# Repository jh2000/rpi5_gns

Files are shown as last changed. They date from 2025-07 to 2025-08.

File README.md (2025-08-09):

# RPi5 HAT+ for GNS AIS and ADS-B Modules

# Aktuelle Fehler
- Im aktuellen Layout ist ein Kreuzungsfehler, dadurch wird UART_Rx an Pin 10 vom GNS5851 mit F_ind verbunden.  
Wird die Platine so gefertigt, muss die Verbindung aufgetrennt werden (direkt vor dem GNS5851, zum Glück sehr gut erreichbar) und manuell eine Brücke von Pin 5 zu R7 gelegt werden.
- Der RX-Pin vom AIS-Modul ist mit GPIO 7 anstelle 8 verbunden, daher ist keine Kommunikation vom RPi zum AIS-Modul möglich. Ein Workaround ist, die nebeneinander liegenden Pins GPIO 7 und 8 (Pins 24 und 26) zu verbinden.
- Das Loch der GPS-Antenne ist scheinbar nicht richtig positioniert, es passt aber noch ausreichend gut. Vermutlich sind die Abstandsmaße von der falschen Seite.
- die Adressierung des PCF8574 ist invertiert On=Low.
- die Seitenpins der ADS-B und AIS Empfängers sind gem. Datenblatt angelegt, sie lassen sich aber nur per Heißluft anlöten, da man von der Seite nicht mit einem Lötkolben an die Pins kommt. Dazu sind sie sehr exakt zu positionieren. Am besten zuerst diese 4 anlöten und prüfen ob etwas gebrückt wurde.
- am AIS-Empfänger sind zusätzliche Lötpunkte an den Gehäuseseiten auf der Platine, die sind aber überflüssig. Ebenso werden ohne Daisy-Chaining die 4 Seitenpins nicht benötigt und könnten auch weg bleiben.

# Allgemein
Schaltplan und Platinendesign mit KiCAD 9.0.  
Im Repo zu finden sind die Projektdateien sowie footprints und symbole der Bauteile der Firma GNS.  
Die RPi HAT Footprints und Symbole stammen aus einem anderen Repo, siehe Links.  
Es gibt ebenso eine Adapterplatine um die AIS/ADSB-Platinen mit allen Pins auf eine Pfostenleiste zu bekommen um z.B. einen ESP32/Arduino o.ä. zu verwenden.  
GNS bietet verschiedene Stufen von Features, die Platinen sind Pinkompatibel, somit lassen sich alternativ zum GNS5894T auch GNS5894TAC oder der abgespeckte GNS 5892R verwenden.  
Das GPS-Modul ist nicht Pinkompatibel mit den anderen. Für AIS gibt es zur Zeit nur ein Modul.  
Anstelle eines RPi5 kann weitestgehend auch ein RPi4 verwendet werden. Es gibt aber im Detail Unterschiede zu beachten, auf die ich hier erst mal nicht näher eingehe.

# Pro&Contra
+ \+ CPU quasi idle
+ \+ dadurch wesentlich energieeffizienter gegenüber SDR/DVB-Sticks
+ \+ mehr Platz für SDR für Schiff-&Flugfunk
+ \- hoher Preis
+ \- nicht alle Feeder kompatibel

# Disclaimer
~~Die Designs sind noch ungeprüft und befinden sich zur Zeit in der Platinenfertigung. Es ist daher ein starker 'work in progress' ohne validierte Layouts.~~  
Die Designs habe ich jeweils einmal fertigen lassen. Dabei sind die oben genannten kleineren Fehler aufgefallen. Grundsätzlich funktionieren die Platinen im aktuellen Zustand.  

**Ich bin eine Privatperson und stehe nicht mit Firma GNS, rpi, jlcpcb oder Anderen in kommerzieller Verbindung**  
**Für Schäden übernehme ich keine Haftung**  

# Beschreibung der Platine
Benutzt werden GNS701 als GPS-Empfänger mit PPS Ausgang, GNS5851 als AIS-Empfänger sowie GNS5894T als ADSB Empfänger.  
Des Weiteren sind ein EEPROM für die HAT+ Erkennung, sowie ein I2C GPIO-Expander (PCF8574AT) vorhanden um die Reset/Steuereingänge anzusteuern.  
Die Adresse des GPIO-Expanders kann über DIP-Schalter frei gewählt werden.  
Das EEPROM zur automatschen HAT Erkennung (z.B. CAT24C128) hat Lötpads um den schreibschutz und die Adresse zu steuern. Standardmäßig ist 0x50. Gem. spezifikation würde auch 0x51 gehen.
Sollte das HAT zusammen mit anderen Verwendet werden muss geprüft werden, dass es keinen Konflikt der Adresse oder Pins gibt.
Aus Platz- und Komplexitätsgründen habe ich auf viele Bauteile verzichtet. Entsprechend fehlen Stütz-/Filterkapazitäten, Pegelbegrenzer usw.  
Es lassen sich theoretisch 2 der AIS Empfänger Chips Daisy-Chainen um auf Kanal A und B zeitgleich zu lauschen. Mit mehr Durchkontaktierungen und den Signalteilern/Filtern/Verstärkern gem. Herstellervorgabe könnte es noch knapp auf die Platine drauf passen. 

# Verdrahtung
Der ADSB-Empfänger hängt an UART0. Hier werden die Flusssteuerung über CTS/RTS (GPIO 16/17, Pin 36/11) mit angesteuert.  
Der AIS-Empfänger hängt an UART3.  
Der GPS-Empfänger hängt an UART4, die PPS Funktion an GPIO26/Pin 37.  

# Konfiguration
die HAT+ Erkennung hat zur Zeit keine funktionalen Benefits, daher müssen alle Einstellungen/Programme selbst getätigt/geladen werden.  
Sobald die Hardware lauffähig getestet ist lassen sich zumindest die overlay Anteile und Pinsteuerungen so automatisieren.
Ich verwende Debian 12.

**/boot/config.txt**
```
dtoverlay=pps-gpio,gpiopin=26  
dtoverlay=uart0-pi5,ctsrts  
dtoverlay=uart3-pi5  
dtoverlay=uart4-pi5
dtparam=i2c1=on
dtoverlay=pcf857x,addr=38 # Wohl obsolet
```
**/etc/default/gpsd**
```
DEVICES="/dev/ttyAMA4 /dev/pps0"
GPSD_OPTIONS="-s 9600 -n"
```

**/etc/ntpsec/ntp.conf**
```
server 127.127.22.0 minpoll 4 maxpoll 4
fudge 127.127.22.0 refid PPS
fudge 127.127.22.0 flag3 1 # enable kernel PLL/FLL clock discipline

server 127.127.28.0 minpoll 4 maxpoll 4 prefer # PPS requires at least one preferred peer
fudge 127.127.28.0 refid GPS
fudge 127.127.28.0 time1 +0.130 # coarse offset due to the UART delay

```
**/etc/ser2net.yaml**
```
connection: &adsb01
    accepter: tcp,4000
    enable: on
    options:
      kickolduser: true
    connector: serialdev,/dev/ttyAMA0,3000000n81,local rtscts # Bei Textmodus
    #    921600n81,local rtscts Bei HULC
connection: &ais01
    accepter: tcp,2001
    enable: on
    options:
      kickolduser: true
    connector: serialdev,/dev/ttyAMA3,115200n81,local
connection: &gps01
    accepter: tcp,3002
    enable: on
    options:
      kickolduser: true
    connector: serialdev,/dev/ttyAMA4,9600n81,local

```
# Peripherie
**Steuerchip PCF8574AT**  
Der GPIO-Expander steuert folgende Funktionen:

|Pin|Funktion|Beschreibung|
|-|-|-|
|P0|ADS-B Reset|low für reset des GNS5894T Receivers, float/high für Betrieb|
|P1|ADS-B Modus|wenn J3 auf 2-3 gebrückt, steuerung des Modus (float/high=Text, low=Binär)
|P2|GPS Reset|low für reset des GNS701 Receivers, float/high für Betrieb|
|P3|GPS Enable|float/high um GNS701 zu aktivieren, low für Standby|
|P4|AIS Reset|low für reset des GNS5851 Receivers, float/high für Betrieb|
|P5|NC|Nicht verbunden|
|P6|NC|Nicht verbunden|
|P7|NC|Nicht verbunden|

Die Adresse des GPIO-Expanders kann über den Dipschalter SW1 zwischen 0x38 und 0x3F frei eingestellt werden.  
Zu beachten ist, dass die DIP-Switche gegen Masse schalten, also On = Masse. Entsprechend ist alle auf On = 0x38 und alle auf Off = 0x3F!

**AIS Modul GNS5851**  
Das AIS-Modul verwendet 115200-8-N-1 für die serielle Kommunikation.  
Beim Power on oder sobald das Modul resetet wird, wird die Version ausgeben:  
$PGNS,0,V,GNS5851,23.20.1,1.0-1,H,S01*08

Es gibt folgende Befehle auf die reagiert wird, jeweils im NMEA 0183 Standard:
Versionsabfrage, $PGNS,V*70<CR><LF>  
Betriebsmodus, $PGNS,M,A*06, $PGNS,M,B*07 oder $PGNS,M,H*0D für nur Kanal *A*, nur *B* oder Kanal*H*opping.  
Nach einem Reset wird die Version ausgegeben.  

**ADS-B Modul GNS5894TAC**  
DAS ADS-B Modul verwendet je nach Einstellung HULC oder Textprotokoll für die ADS-B Daten mit entsprechend 921600 oder 3000000 Baud, je 8 N 1.  
Aufgrund der Datenrate ist die Verwendung von RTS/CTS Handshakes empfohlen.  
Im HULC Modus wird sekündlich ein Datenpaket übertragen, im Textmodus dagegen gibt es abseits empfangener Signale keinerlei Status, auch nicht beim Reset/Einschalten.  
Die Funktionsfähigkeit kann hier getestet werden indem "#00" gesendet wird.

Das Modul empfängt auf dem 2. UART Port die GPS Daten vom GNS701 und erwartet diese mit 9600 Baud und einer Position pro Sekunde. Benutzt wird dafür der 2. Ausgang des GPS-Empfängers.

Es gibt folgende Befehle, je nach Protokoll:
Versionsabfrage, #00<CR><LF>  
Betriebsmodus abfragen, #43<CR><LF>  
Betriebsmodus setzen, #43-XY<CR><LF> wobei X 1 für MLAT sowie 8 für RSSI ist und Y die Ausgabe steuert (0 Mode S off, 1 'reserved, do not use', 2 Output all Mode-S  & Mode-A/C data, default, 3 nur ADS-B und 4 nur ADS-B mit gültigem CRC)  
Reset, #FF<CR><LF>  

**GPS Modul GNS701**  
Bei der Konfiguration des GPS-Empfängers zu beachten, dass die Daten des 2. Ausganges (TX1) an das ADS-B Modul gehen.  
Standardmäßig werden 9600 Baud, 8-N-1 mit einer Position pro Sekunde  benutzt für beide Schnittstellen.  
Solange das Modul im Reset oder Standby zustand ist, bleibt die 3D-Fix LED aus. Solange das Modul ansonsten im Normalbetrieb ist, sollte mindestens einmal pro Sekunde etwas im Terminal zu finden sein, im Takt mit dem Blinken der 3D-Fix LED.

Die Konfiguration basiert auf der MediaTek Befehlsreferenz. Entsprichend sollten die dortigen Befehle gehen  
Testpaket: $PMTK000*32<CR><LF>  
Versionsabfrage: $PMTK604*6D<CR><LF>  

**Allgemein**  
Die Module geben über die UART-Schnittstelle standardmäßig (lesbaren) Text aus. Es kann für ADS-B aber auch das HULC/Beast Binärformat anstelle von AVR benutzt werden.
Alle üblichen Programme können die Daten entsprechend lesen, bis auf modesdeco2, welches nur Funkrohdaten verarbeiten kann.  

Erfolgreich getestete feeder für AIS mit dem GNS5851:  
+ sxfeeder
+ AIS-Catcher

Erfolgreich getestete feeder für ADS-B mit dem GNS5894T:  
+ rbfeeder (radarbox)
+ feed-adsbx (adsbexchange)
+ mlat-client (adsbexchange)
+ fr24feed (flightradar)

Das GPS-Modul bietet GPS und PPS Daten für z.B. gpsd.  

In der Zielarchitektur verwende ich gpsd, ser2net und alle Feeder der jeweiligen Platformen.  
Dabei werden die AIS und ADS-B rohdaten via ser2net vom jeweiligen primärprogramm (AIS-Catcher, rbfeeder) gelesen und stellen diese Daten dann an sekundärfeeder (sxfeeder, feed-adsb usw...) bereit.
ser2net hat sich als praktisch erwiesen, da es sich einfach debuggen lässt indem man z.b. per nc oder telnet verbinden kann.  
gpsd und ntpd stellen dem System die genauen Zeitdaten bereit. Wer es richtig übertreiben will, kann das Design anpassen und einen RTK fähigen GPS Empfänger einbauen.

Das HAT sollte HAT+ Spezifikationen erfüllen, dies ist aber noch nicht bestätigt, im Design ist testweise ein HAT+ Logo angebracht.

Im aktuellen Design gegenüber dem Referenzentwurf fehlt der Schlitz um an einen der CSI Ports zu kommen. Da dies ggf. Bestandteil der HAT+ Hardwareforderungen ist, muss dies noch korrigiert werden.  
Diese Abweichung zeigt KiCAD entsprechend als Warnung an.  
Des Weiteren werden die je 4 zusätzlichen Pads der AIS und ADS-B Module als zu eng für die Standardabstände geflaggt. Somit sollten anfangs 1+3+3 Warnungen bzw. Fehler auftreten, welche ignoriert werden können.

# Linksammlung:

+ HAT+ Spezifikation: [https://datasheets.raspberrypi.com/hat/hat-plus-specification.pdf]
+ GPS: [https://www.gns-electronics.de/product/gns-701/]
+ AIS: [https://www.gns-electronics.de/product/gns-5851-ais-module/]
+ AIS Daisy-Chaining: [https://www.gns-electronics.de/wp-content/uploads/2025/05/GNS5851_AppNote_2ch-Receiver-V0.9.pdf]
+ ADS-B: [https://www.gns-electronics.de/product/gns-5894-highperformance-ads-b-modul/]
+ RPi HAT Template: [https://github.com/devbisme/RPi_Hat_Template]
+ Prototypenfertiger: [https://jlcpcb.com/]
+ PMTK Protokoll: [https://cdn.sparkfun.com/assets/f/0/9/1/c/PMTK_Protocol.pdf]

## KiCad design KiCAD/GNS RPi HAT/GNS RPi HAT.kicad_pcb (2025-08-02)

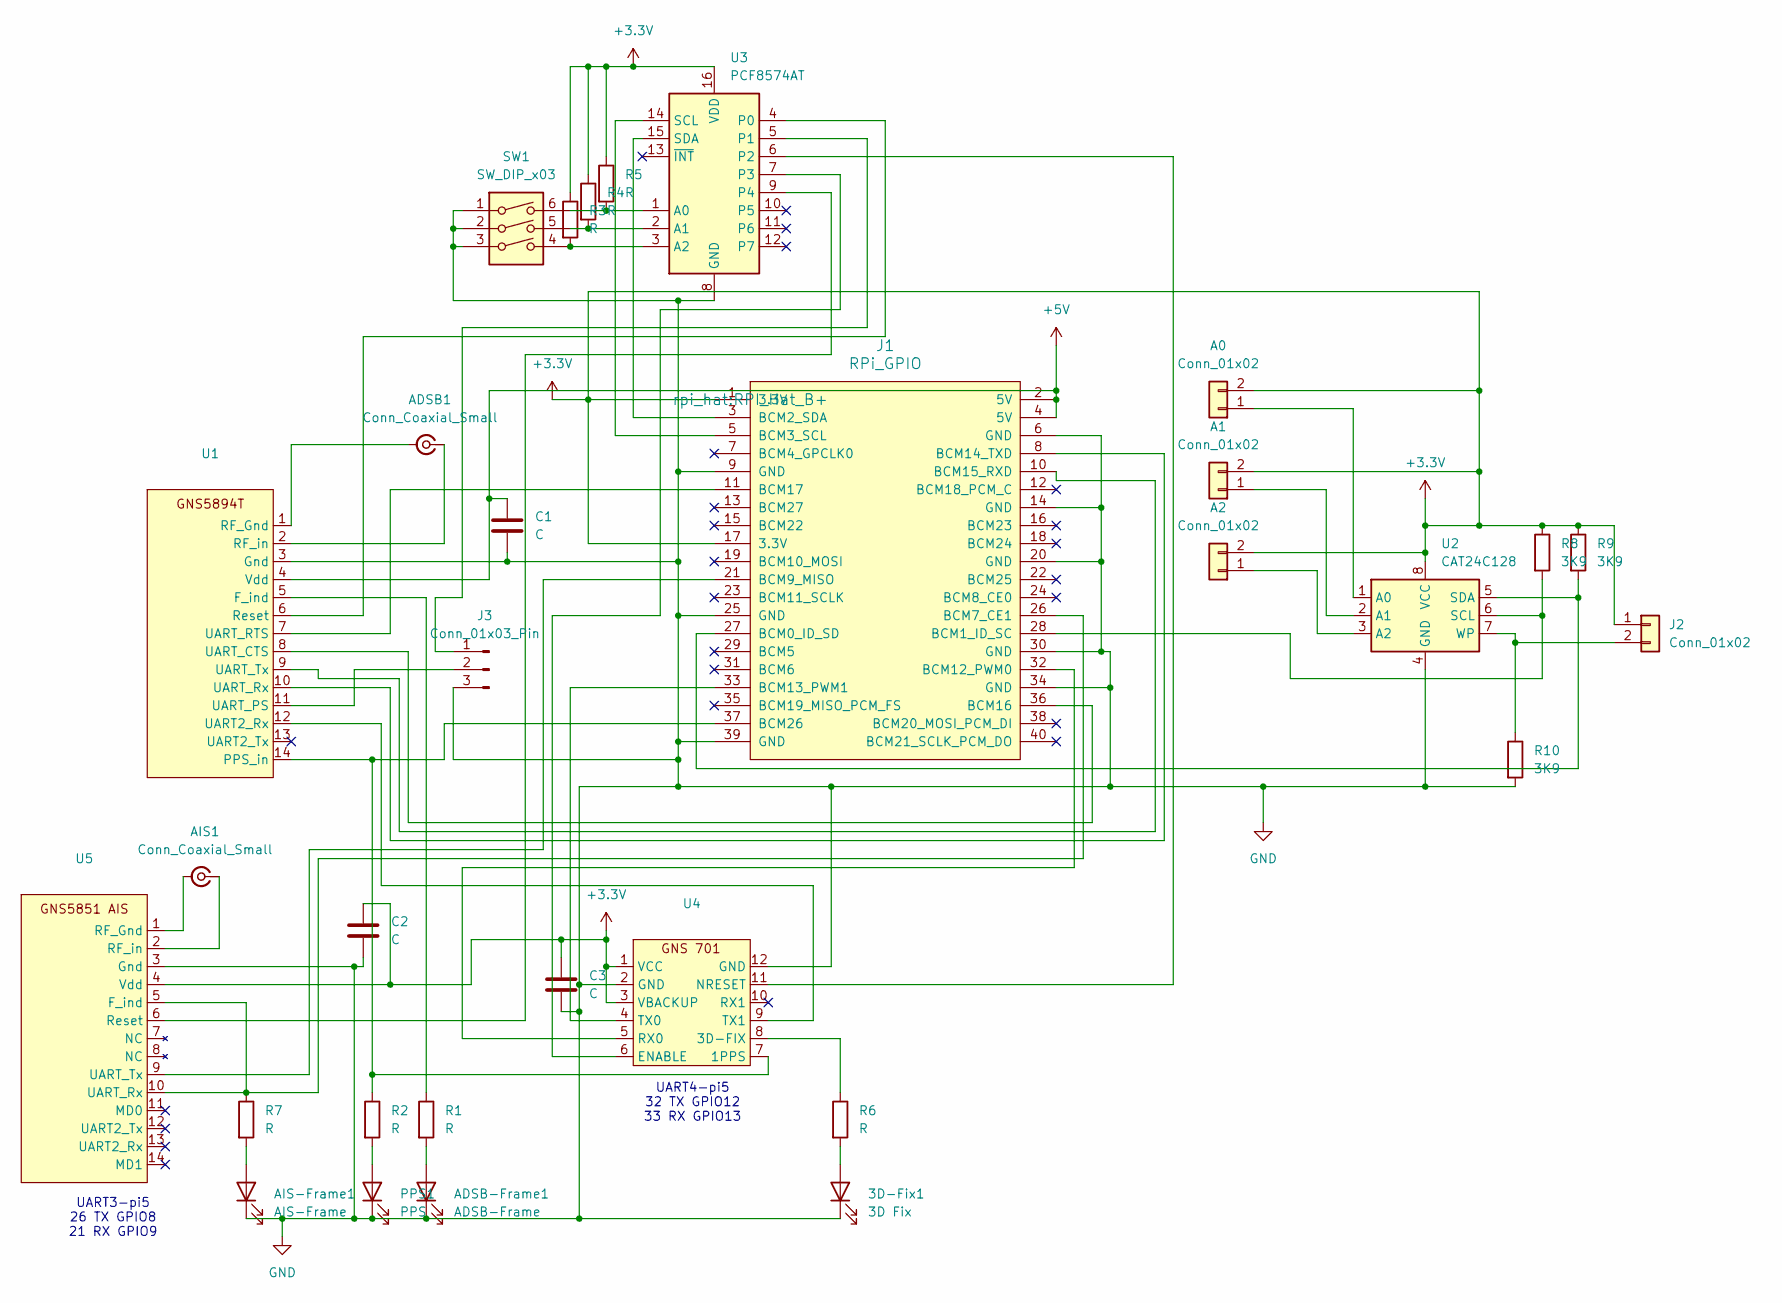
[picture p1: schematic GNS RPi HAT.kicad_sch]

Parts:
3D-Fix1: 3D Fix; LED_0805_2012Metric_Pad1.15x1.40mm_HandSolder
A0, A1, A2: Conn_01x02; SolderJumper-2_P1.3mm_Open_Pad1.0x1.5mm
ADSB1: Conn_Coaxial_Small; SMA_Amphenol_901-144_Vertical
ADSB-Frame1: ADSB-Frame; LED_0805_2012Metric_Pad1.15x1.40mm_HandSolder
AIS1: Conn_Coaxial_Small; SMA_Amphenol_901-144_Vertical
AIS-Frame1: AIS-Frame; LED_0805_2012Metric_Pad1.15x1.40mm_HandSolder
C1, C2, C3: C; C_0805_2012Metric_Pad1.18x1.45mm_HandSolder
J1: RPi_GPIO; RPI_Hat_B+
J2: Conn_01x02; PinSocket_1x02_P2.54mm_Vertical
J3: Conn_01x03_Pin; PinHeader_1x03_P2.54mm_Vertical
PPS1: PPS; LED_0805_2012Metric_Pad1.15x1.40mm_HandSolder
R1, R2, R3, R4, R5, R6, R7: R; R_0805_2012Metric_Pad1.20x1.40mm_HandSolder
R8, R9, R10: 3K9; R_0805_2012Metric_Pad1.20x1.40mm_HandSolder
SW1: SW_DIP_x03; SW_DIP_SPSTx03_Slide_9.78x9.8mm_W7.62mm_P2.54mm
U1: GNS5894T
U2: CAT24C128; SOIC-8_3.9x4.9mm_P1.27mm
U3: PCF8574AT; SOIC-16W_7.5x10.3mm_P1.27mm
U4: GNS701
U5: GNS5851

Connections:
+3.3V: A0.2, A1.2, A2.2, C2.1, C3.1, J1.1 (3.3V), J1.17 (3.3V), J2.1, R3.1, R4.1, R5.1, R8.1, R9.1, U2.8 (VCC), U3.16 (VDD), U4.1 (VCC), U4.3 (VBACKUP), U5.4 (Vdd)
+5V: C1.1, J1.2 (5V), J1.4 (5V), U1.4 (Vdd)
GND: 3D-Fix1.1 (K), ADSB-Frame1.1 (K), AIS-Frame1.1 (K), C1.2, C2.2, C3.2, J1.6 (GND), J1.9 (GND), J1.14 (GND), J1.20 (GND), J1.25 (GND), J1.30 (GND), J1.34 (GND), J1.39 (GND), J3.3, PPS1.1 (K), R10.2, SW1.1, SW1.2, SW1.3, U1.3 (Gnd), U2.4 (GND), U3.8 (GND), U4.2 (GND), U4.12 (GND), U5.3 (Gnd)
unnamed: 3D-Fix1.2 (A), R6.2
unnamed: A0.1, U2.1 (A0)
unnamed: A1.1, U2.2 (A1)
unnamed: A2.1, U2.3 (A2)
unnamed: ADSB1.2 (Ext), U1.1 (RF_Gnd)
unnamed: ADSB1.1 (In), U1.2 (RF_in)
unnamed: ADSB-Frame1.2 (A), R1.2
unnamed: AIS1.2 (Ext), U5.1 (RF_Gnd)
unnamed: AIS1.1 (In), U5.2 (RF_in)
unnamed: AIS-Frame1.2 (A), R7.2
unnamed: J1.27 (BCM0_ID_SD), R9.2, U2.5 (SDA)
unnamed: J1.28 (BCM1_ID_SC), R8.2, U2.6 (SCL)
unnamed: J1.3 (BCM2_SDA), U3.15 (SDA)
unnamed: J1.5 (BCM3_SCL), U3.14 (SCL)
unnamed: J1.26 (BCM7_CE1), R7.1, U5.5 (F_ind), U5.10 (UART_Rx)
unnamed: J1.21 (BCM9_MISO), U5.9 (UART_Tx)
unnamed: J1.32 (BCM12_PWM0), U4.5 (RX0)
unnamed: J1.33 (BCM13_PWM1), U4.4 (TX0)
unnamed: J1.8 (BCM14_TXD), U1.10 (UART_Rx)
unnamed: J1.10 (BCM15_RXD), U1.9 (UART_Tx)
unnamed: J1.36 (BCM16), U1.8 (UART_CTS)
unnamed: J1.11 (BCM17), U1.7 (UART_RTS)
unnamed: J1.37 (BCM26), R2.1, U1.14 (PPS_in), U4.7 (1PPS)
unnamed: J2.2, R10.1, U2.7 (WP)
unnamed: J3.1, U3.5 (P1)
unnamed: J3.2, U1.11 (UART_PS)
unnamed: PPS1.2 (A), R2.2
unnamed: R1.1, U1.5 (F_ind)
unnamed: U1.6 (Reset), U3.4 (P0)
unnamed: U1.12 (UART2_Rx), U4.9 (TX1)
unnamed: R5.2, SW1.6, U3.1 (A0)
unnamed: R4.2, SW1.5, U3.2 (A1)
unnamed: R3.2, SW1.4, U3.3 (A2)
unnamed: U3.6 (P2), U4.11 (NRESET)
unnamed: U3.7 (P3), U4.6 (ENABLE)
unnamed: U3.9 (P4), U5.6 (Reset)
unnamed: R6.1, U4.8 (3D-FIX)

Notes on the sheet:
UART4-pi5 32 TX GPIO12 33 RX GPIO13
UART3-pi5 26 TX GPIO8 21 RX GPIO9

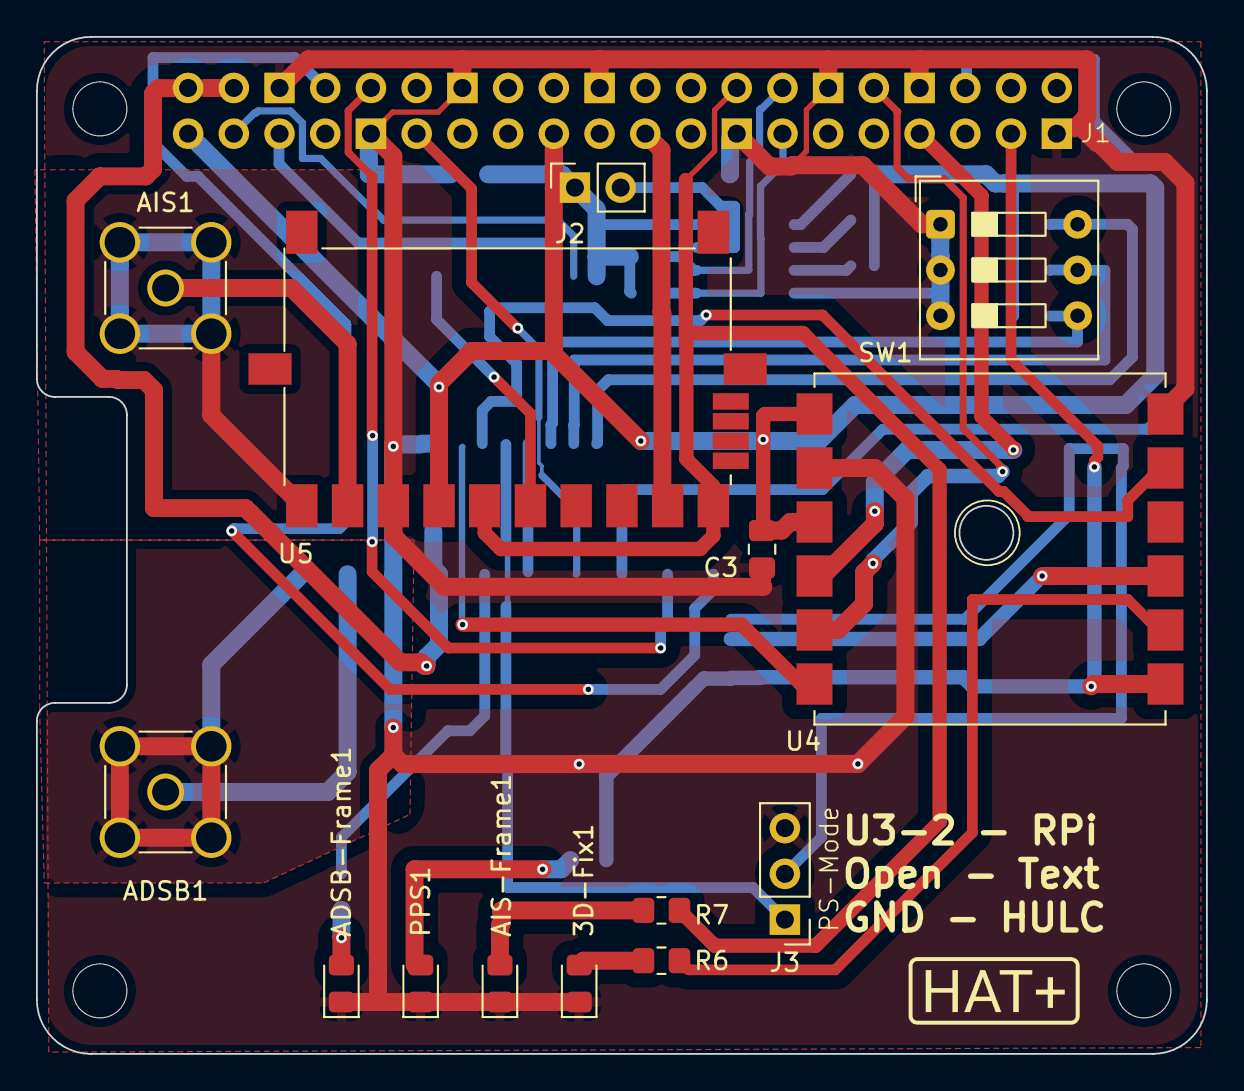
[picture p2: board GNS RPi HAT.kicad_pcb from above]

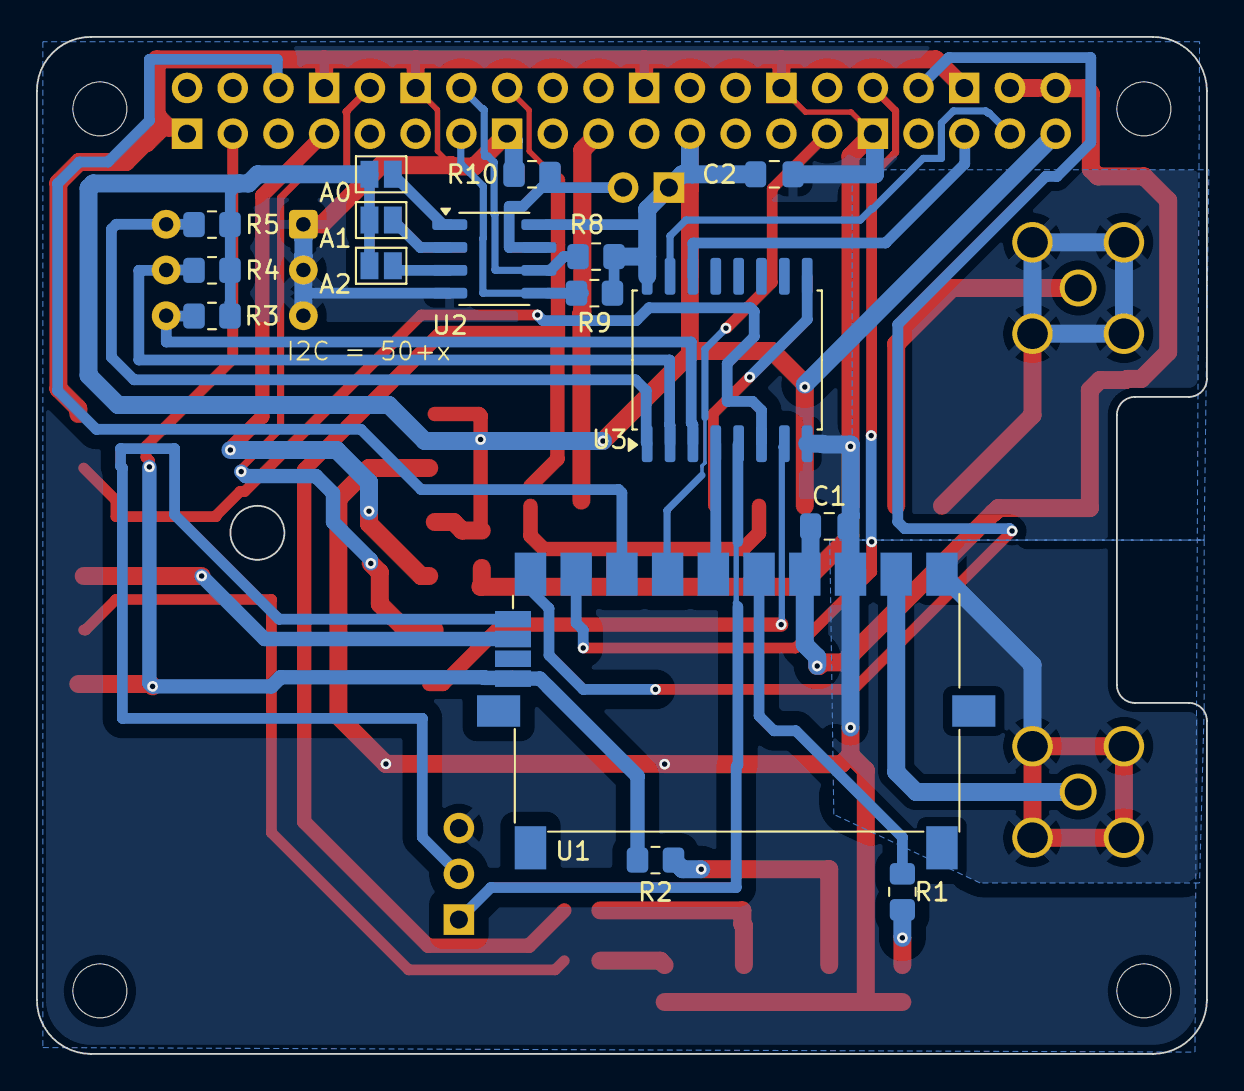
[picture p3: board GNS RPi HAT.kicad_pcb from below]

Board: 2 copper layers, 65.0 x 56.5 mm, 31 parts (16 on the bottom side), 40 nets.

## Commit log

2025-08-02 Wechsel auf SMD-Bauteile, Fehlerkorrekturen
    Die Widerstände und Leds wurden auf noch von Hand Lötbare SMD-Varianten geändert.
    Die Platine wurde weiter aufgeräumt.
    Wichtigste Änderung: die Adressierung des I2C Busses für die HAT+ Erkennung wurde von einer fixen Adresse auf Lötpads geändert.
    Die Adressen 0x50, 0x51 und ggf. später weitere sind nun möglich um im Abhängigkeit zu anderen HAT keinen Adresskonflikt zu verursachen.
    Das erste Design hatte noch fix die Adresse 0x5F, welcher in der Spec nicht automatisch erkannt wird.
    Der Schreibschutz ist ebenfalls über eine Lötbrücke steuerbar.
    [GNS RPi HAT.kicad_pcb, GNS RPi HAT.kicad_sch]
2025-08-02 Update README.md
    Fehlerkorrekturen, Anpassungen der HAT+ Erkennung.
2025-08-02 Update README.md
    Anpassung an aktuellen Erkenntnisstand.
    - Aufnahme der GPIO-Expander Pins
    - Aufnahme der Schnittstellenparameter
2025-08-08 Update README.md
    Erkenntnisse der ersten Fertigungscharge eingearbeitet.
    Prototypplatine funktioniert Grundsätzlich, es sind aber ein paar nacharbeiten zur Korrektur eines Fehlers notwendig.
2025-08-09 Update README.md
    Weiterer Fehler im Design zum AIS-RX Pin.
